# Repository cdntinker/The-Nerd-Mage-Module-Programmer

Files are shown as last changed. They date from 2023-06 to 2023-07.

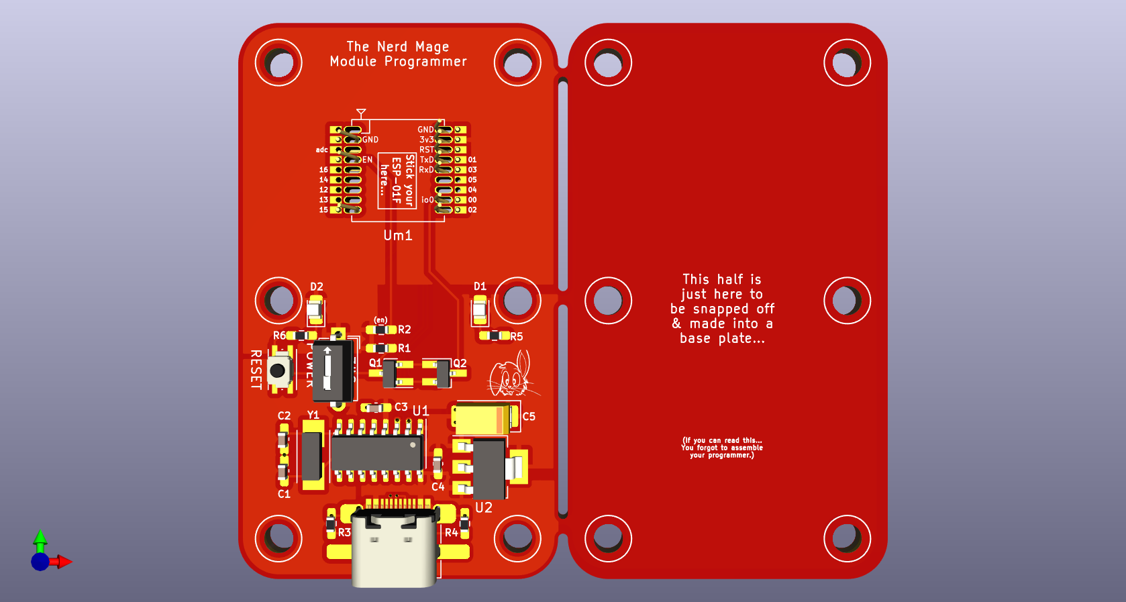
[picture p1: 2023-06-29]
Pix/ESP-01F (front).png

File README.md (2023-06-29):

# This is __The Nerd Mage Module Programmer__  Project

The original intent of this project was to simplify pre-programming ESP modules.

I started out doing up a design to help a friend program ESP-M3 modules with OTA capable firmware that he could then solder into projects to be scattered around And never directly connected again.

And, of course, The rabbits showed up & started digging holes in my desktop...  As usual...

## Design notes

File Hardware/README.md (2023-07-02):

# This is __The Nerd Mage Module Programmer__  Project

Each of the subfolders here is basically a KiCAD project.  Yes, I know there's a lot of duplication here.  One of these days, I'll figure out how to make KiCAD re-use existing schematics & board files as "libraries".

- (KiCAD Customs)
  - Custom symbols, footprints, 3D models needed for this project
    - (Just the 3D models so far...)

## The various "editions"...

- (blank)
  - The base design with no module set up
- (standalone)
  - A version with a pin header instead of a module
- ESP-01F
  - Footprint added for an ESP-01F
- ESP-01S
  - Footprint added for an ESP-01S
- ESP-M3
  - Footprint added for an ESP-M3
- ESP-12
  - Footprint added for an ESP-12 (or ESP-07)
- ESP-Wroom-32
  - Footprint added for an ESP-Wroom-32
- Seeed Wio-RP2040
  - This one is VERY MUCH a WIP
  - Building & adding a footprint for the Seeed Studios Wio-RP2040 module
- BOM.ods
  - Sort of a manually created Bill of Materials

  ## To be done

  Need to work out how to add my custom symbols, footprints & 3D models in here...

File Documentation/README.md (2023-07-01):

# This is __The Nerd Mage Module Programmer__  Project

Really should expand on this...

## Notes about the common design elements of the boards

### The __reset / io0__ "MCU Mode Select" circuit:
Transistors Q1 & Q2 are a bright idea stolen blatantly from the schematic of the Wemos D1-mini.  Basically, they cause io0 to be held low during a reset called for programatically.

So...  You can treat these programmers as nodemcu boards.

- In platformio.ini:
  - `upload_resetmethod = nodemcu`

### The CH340 UART chip:
This is a basic USB to serial chip.

The version used in the current design (CH340G) uses an external crystal for timing.

__NOTE__ that the RxD & TxD lines from this chip are swapped on their way to the module.

### The USB connector (J1):
These boards use USB-C simply for the convenience of reversability.  The USB connection is actually just USB 2.0.

R3 & R4 are there to ensure that, if your USB port on the computer is USB-C, then 5.0V is supplied to the board.

### The LEDs:
- D1
  - indicates power to the board (From USB...)
- D2
  - Indicates power to the module being programmed

### The switches:
- SW1 (pushbutton)
  - Pulls the reset line of the module low
- SW2 (slider)
  - Switches on/off power to the module

### The "Base Plate" board:
The flexyPins used for connecting the modules require space under the board.

So...  The base plate, along with 6 3mmx4mm spacers & 12 of the shortest available 3mm machine screws provide this space & protect the FlexyPins.

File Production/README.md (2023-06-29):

# This is __The Nerd Mage Module Programmer__  Project

- CH340-testing.020.AS_FABBED.tar.gz
  - is the fully tested version.
- CH340-testing.AS_FABBED.tar.gz
  - is only still here since I have a few boards of that version on hand.  The Rx & Tx lines are backwards...
- 0.5.2 (ESP12) (as fabbed).tar.gz
  - is the NEW & IMPROVED design.  This particular one is the ESP-12 programmer as requested by TheGuruOfNothing.

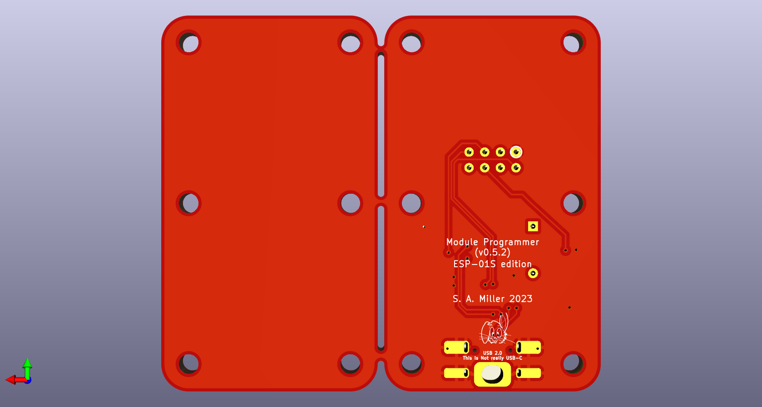
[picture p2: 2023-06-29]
Pix/ESP-01S (back).png

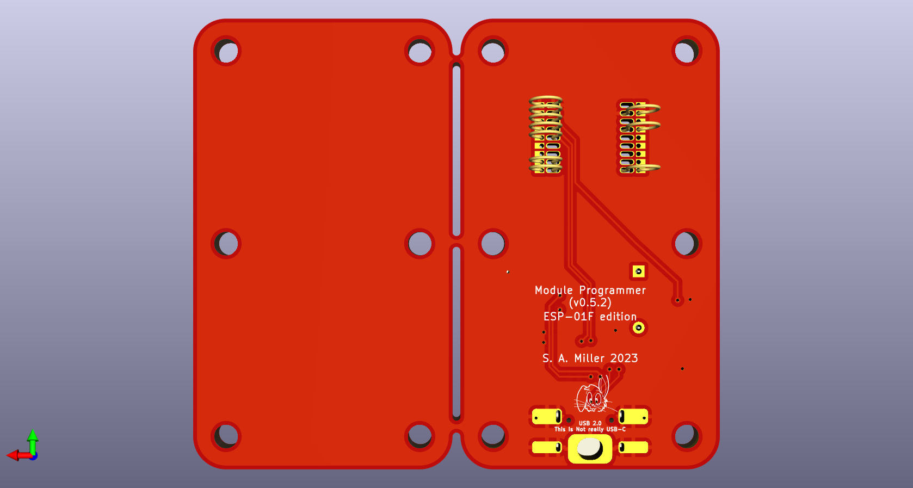
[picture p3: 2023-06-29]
Pix/ESP-01F (back).png

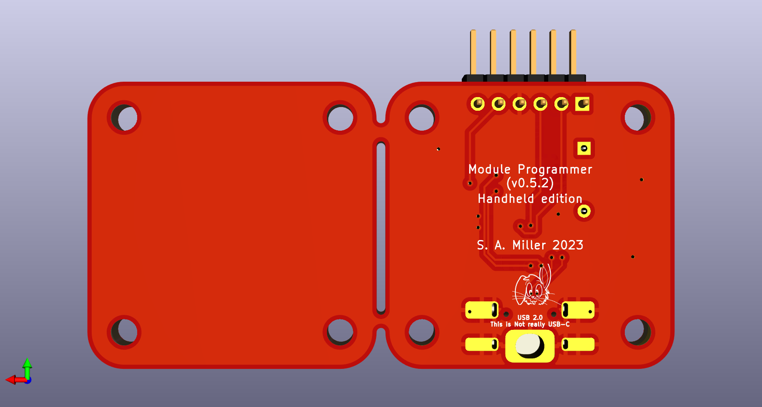
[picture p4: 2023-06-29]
Pix/Standalone (back).png

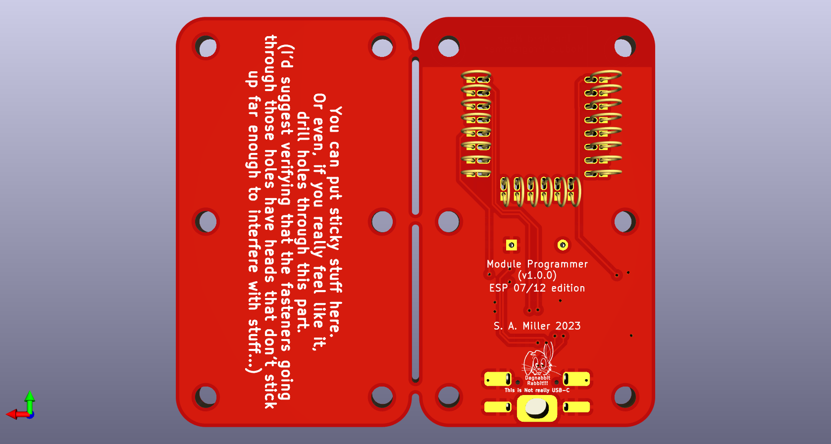
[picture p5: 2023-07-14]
Pix/ESP12 (1.0.0) (back).png

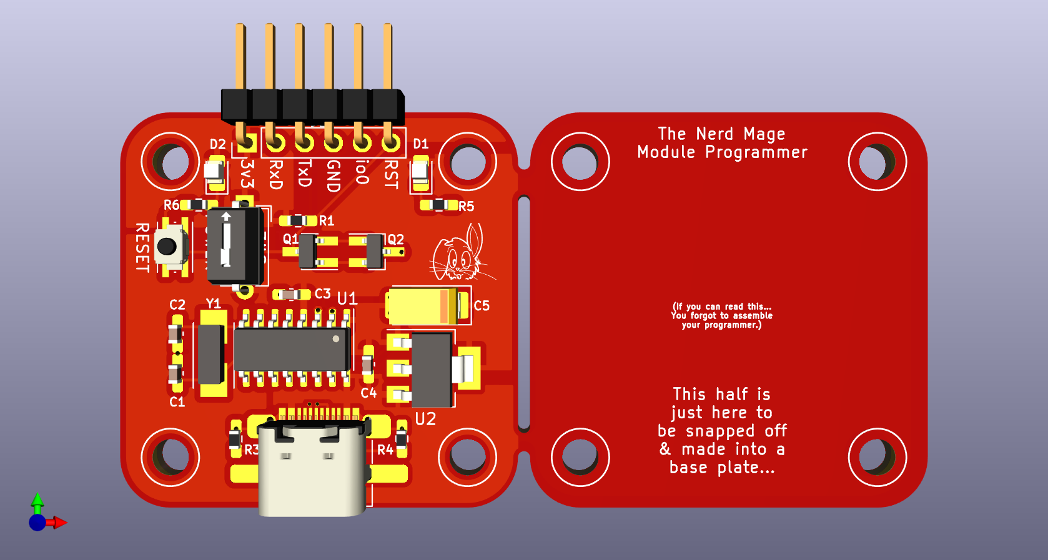
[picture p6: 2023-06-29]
Pix/Standalone (front).png

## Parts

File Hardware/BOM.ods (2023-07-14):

 |  | Value | Type | Footprint | Stock | Order? | Link
Boards
 |  |  |  |  |  |  |  | 1.5
Ics
 | U1 | CH340G | USB 2.0 Transceiver | SOP-16 | 16 |  | https://www.lcsc.com/product-detail/USB-ICs_WCH-Jiangsu-Qin-Heng-CH340G_C14267.html | 0.4805
 | U2 | AMS1117-3.3 | Linear Voltage Regulator | SOT-223 | 80 |  | https://www.lcsc.com/product-detail/Linear-Voltage-Regulators-LDO_HEERMICR-AMS1117-3-3_C5199435.html | 0.0627
Transistors
 | Q1 | MMBT3904 | NPN | SOT-23 | 70 |  | https://www.lcsc.com/product-detail/Bipolar-Transistors-BJT_GOODWORK-MMBT3904_C909754.html | 0.0057
 | Q2 | MMBT3904 | NPN | SOT-23 |  |  | https://www.lcsc.com/product-detail/Bipolar-Transistors-BJT_GOODWORK-MMBT3904_C909754.html | 0.0057
Xtals
 | Y1 | 12MHz | Quartz Crystam | 5.0x3.2x1.3 | 6 |  | https://www.lcsc.com/product-detail/Crystals_HCI-XC53G2-12-000-F20LJDT_C2842275.html | 0.1838
LEDs
 | D1 | LED | Green | 0805 | 20 |  | https://www.lcsc.com/product-detail/_Yongyu-Photoelectric-_C434432.html | 0.0123
 | D2 | LED | Blue | 0805 | 20 |  | https://www.lcsc.com/product-detail/_Yongyu-Photoelectric-_C434433.html | 0.012
Resistors
 | R1 | 10K | Thick Film | 0603 | 200 |  | https://www.lcsc.com/product-detail/Chip-Resistor-Surface-Mount_UNI-ROYAL-Uniroyal-Elec-0603WAF1002T5E_C25804.html | 0.0009
 | R2 | 10K | Thick Film | 0603 |  |  | https://www.lcsc.com/product-detail/Chip-Resistor-Surface-Mount_UNI-ROYAL-Uniroyal-Elec-0603WAF1002T5E_C25804.html | 0.0009
 | R3 | 5K1 | Thick Film | 0603 | 50 |  | https://www.lcsc.com/product-detail/Chip-Resistor-Surface-Mount_UNI-ROYAL-Uniroyal-Elec-0603WAF5101T5E_C23186.html | 0.0011
 | R4 | 5K1 | Thick Film | 0603 |  |  | https://www.lcsc.com/product-detail/Chip-Resistor-Surface-Mount_UNI-ROYAL-Uniroyal-Elec-0603WAF5101T5E_C23186.html | 0.0011
 | R5 | 2K2 | Thick Film | 0603 | 90 |  | https://www.lcsc.com/product-detail/Chip-Resistor-Surface-Mount_UNI-ROYAL-Uniroyal-Elec-0603WAF2201T5E_C4190.html | 0.0011
 | R6 | 2K2 | Thick Film | 0603 |  |  | https://www.lcsc.com/product-detail/Chip-Resistor-Surface-Mount_UNI-ROYAL-Uniroyal-Elec-0603WAF2201T5E_C4190.html | 0.0011
 | R7 | 10K | Thick Film | 0603 |  |  | https://www.lcsc.com/product-detail/Chip-Resistor-Surface-Mount_UNI-ROYAL-Uniroyal-Elec-0603WAF1002T5E_C25804.html | 0.0009
 | R8 | 10K | Thick Film | 0603 |  |  | https://www.lcsc.com/product-detail/Chip-Resistor-Surface-Mount_UNI-ROYAL-Uniroyal-Elec-0603WAF1002T5E_C25804.html | 0.0009
Caps
 | C1 | 20p | MLCC | 0603 | 40 |  | https://www.lcsc.com/product-detail/Multilayer-Ceramic-Capacitors-MLCC-SMD-SMT_YAGEO-CC0603JRNPO9BN220_C105620.html | 0.0023
 | C2 | 20p | MLCC | 0603 | 200 |  | https://www.lcsc.com/product-detail/Multilayer-Ceramic-Capacitors-MLCC-SMD-SMT_YAGEO-CC0603JRNPO9BN220_C105620.html | 0.0023
 | C3 | 10nf | MLCC | 0603 | 200 |  | https://www.lcsc.com/product-detail/Multilayer-Ceramic-Capacitors-MLCC-SMD-SMT_YAGEO-CC0603KRX7R9BB103_C100042.html | 0.0021
 | C4 | 100nf | MLCC | 0603 | 200 |  | https://www.lcsc.com/product-detail/Multilayer-Ceramic-Capacitors-MLCC-SMD-SMT_FH-Guangdong-Fenghua-Advanced-Tech-0603F104M500NT_C42998.html | 0.0022
 | C5 | 22uf | Tantalum |  | 90 |  | https://www.lcsc.com/product-detail/Tantalum-Capacitors_Vishay-Intertech-293D226X0016C2TE3_C1957020.html | 0.3234
Connectors
 | J1 | USB-C |  |  |  |  | https://www.lcsc.com/product-detail/USB-Connectors_SHOU-HAN-TYPE-C-16PIN-2MD-073_C2765186.html | 0.0523
 | Um1 | FlexyPins |  |  | 60 |  | https://www.lectronz.com/products/flexypin-pack-of-100 | 1
 |  |  |  |  | 150
Switches
 | SW1 | pushbutton |  |  | 20 |  | https://www.lcsc.com/product-detail/Tactile%20Switches_SHOU-HAN-TS273014TP-180gf-098_C2858276.html | 0.1074
 | SW2 | DIP-1 |  |  | 17 |  | https://www.lcsc.com/product-detail/DIP-Switches_C-K-SDA01H1BD_C2689618.html | 0.7732
 |  |  |  |  |  |  |  | 4.5359

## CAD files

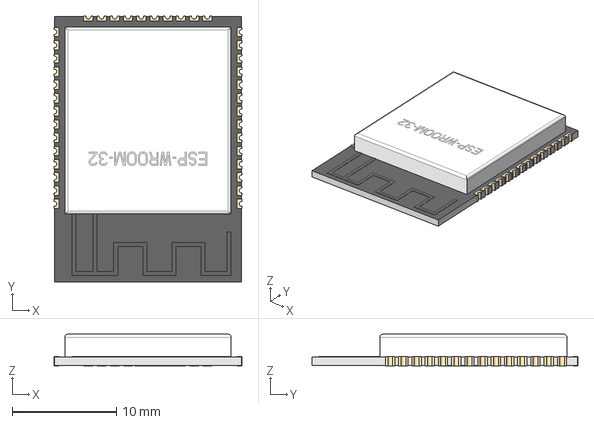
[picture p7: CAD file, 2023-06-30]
Hardware/(KiCAD Customs)/3D/ESP32/KiCAD-ESP-WROOM-32.step
18.1 x 25.5 x 3.04 mm

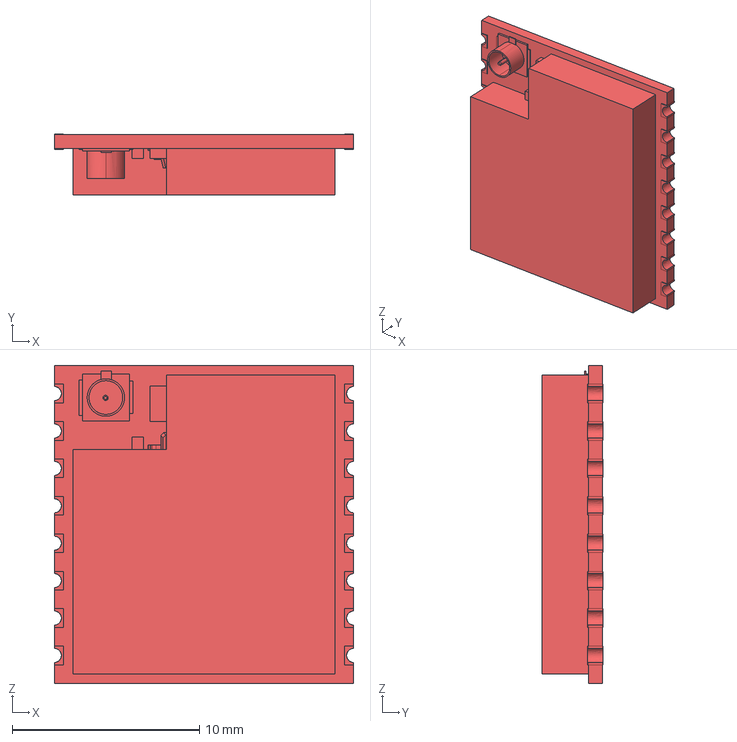
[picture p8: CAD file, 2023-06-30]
Hardware/(KiCAD Customs)/3D/ESP8266/esp-07s.stp
16.0 x 3.28 x 17.0 mm

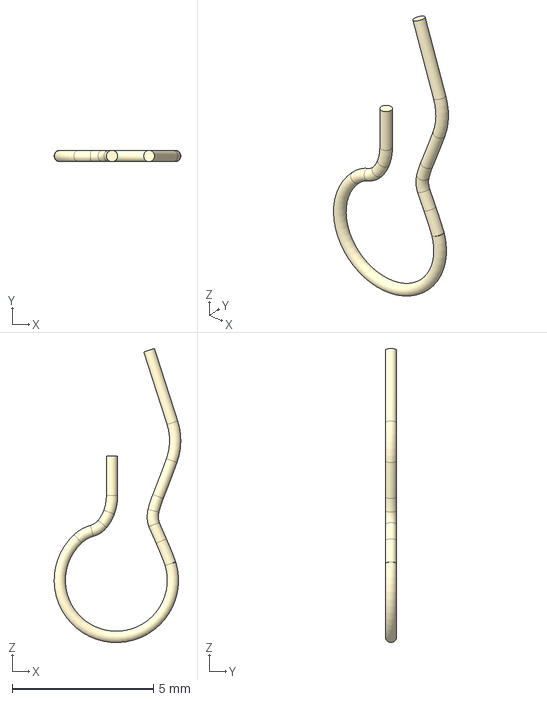
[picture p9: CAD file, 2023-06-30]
Hardware/(KiCAD Customs)/3D/flexypin.step
4.48 x 0.4 x 10.4 mm

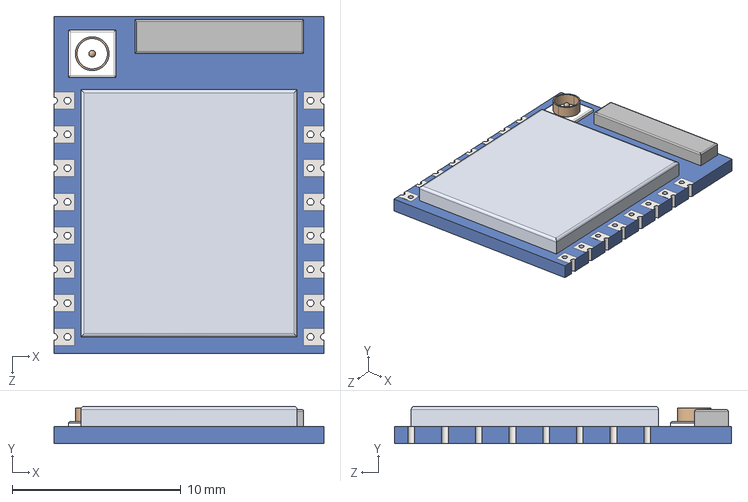
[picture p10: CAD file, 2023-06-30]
Hardware/(KiCAD Customs)/3D/ESP8266/ESP8266-ESP07.STEP
16.0 x 2.21 x 20.0 mm

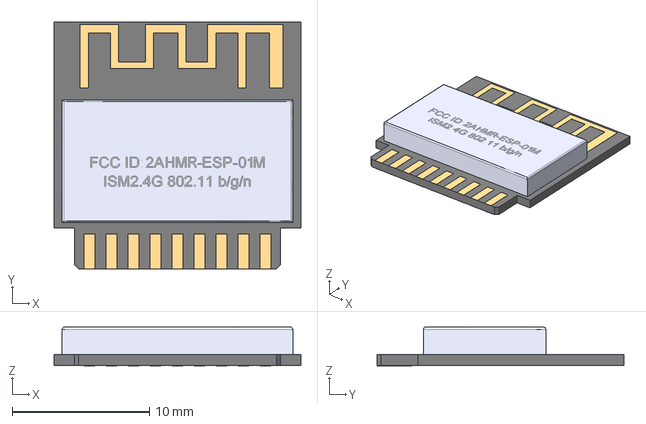
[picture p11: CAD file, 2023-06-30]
Hardware/(KiCAD Customs)/3D/ESP8266/ESP-01M.stp
18.0 x 18.0 x 2.81 mm

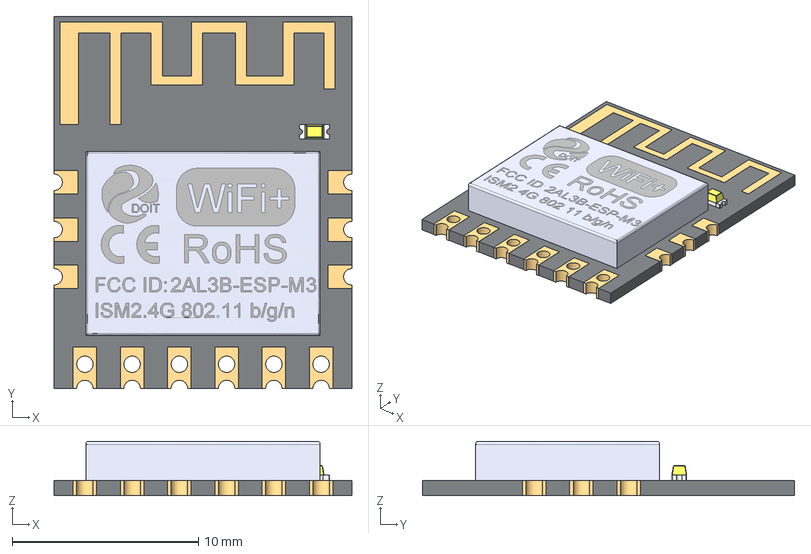
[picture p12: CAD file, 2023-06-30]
Hardware/(KiCAD Customs)/3D/ESP8266/ESP-M3.stp
16.0 x 20.0 x 2.91 mm

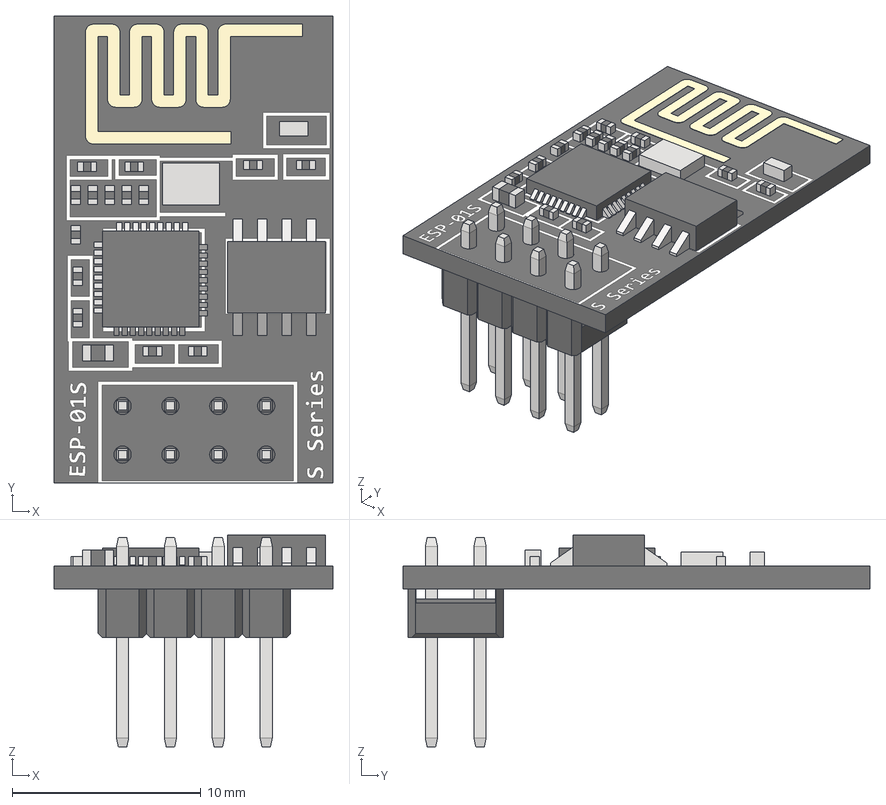
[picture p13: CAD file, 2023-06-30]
Hardware/(KiCAD Customs)/3D/ESP8266/ESP-01S (ESP8266) Board Module.step
14.8 x 24.8 x 11.2 mm
PCB
Antenna
SerialFlashMem
ESP8266EX
Male Pin Header 2x4
SmalComponent x 14
LargeComponent
LED
Crystal

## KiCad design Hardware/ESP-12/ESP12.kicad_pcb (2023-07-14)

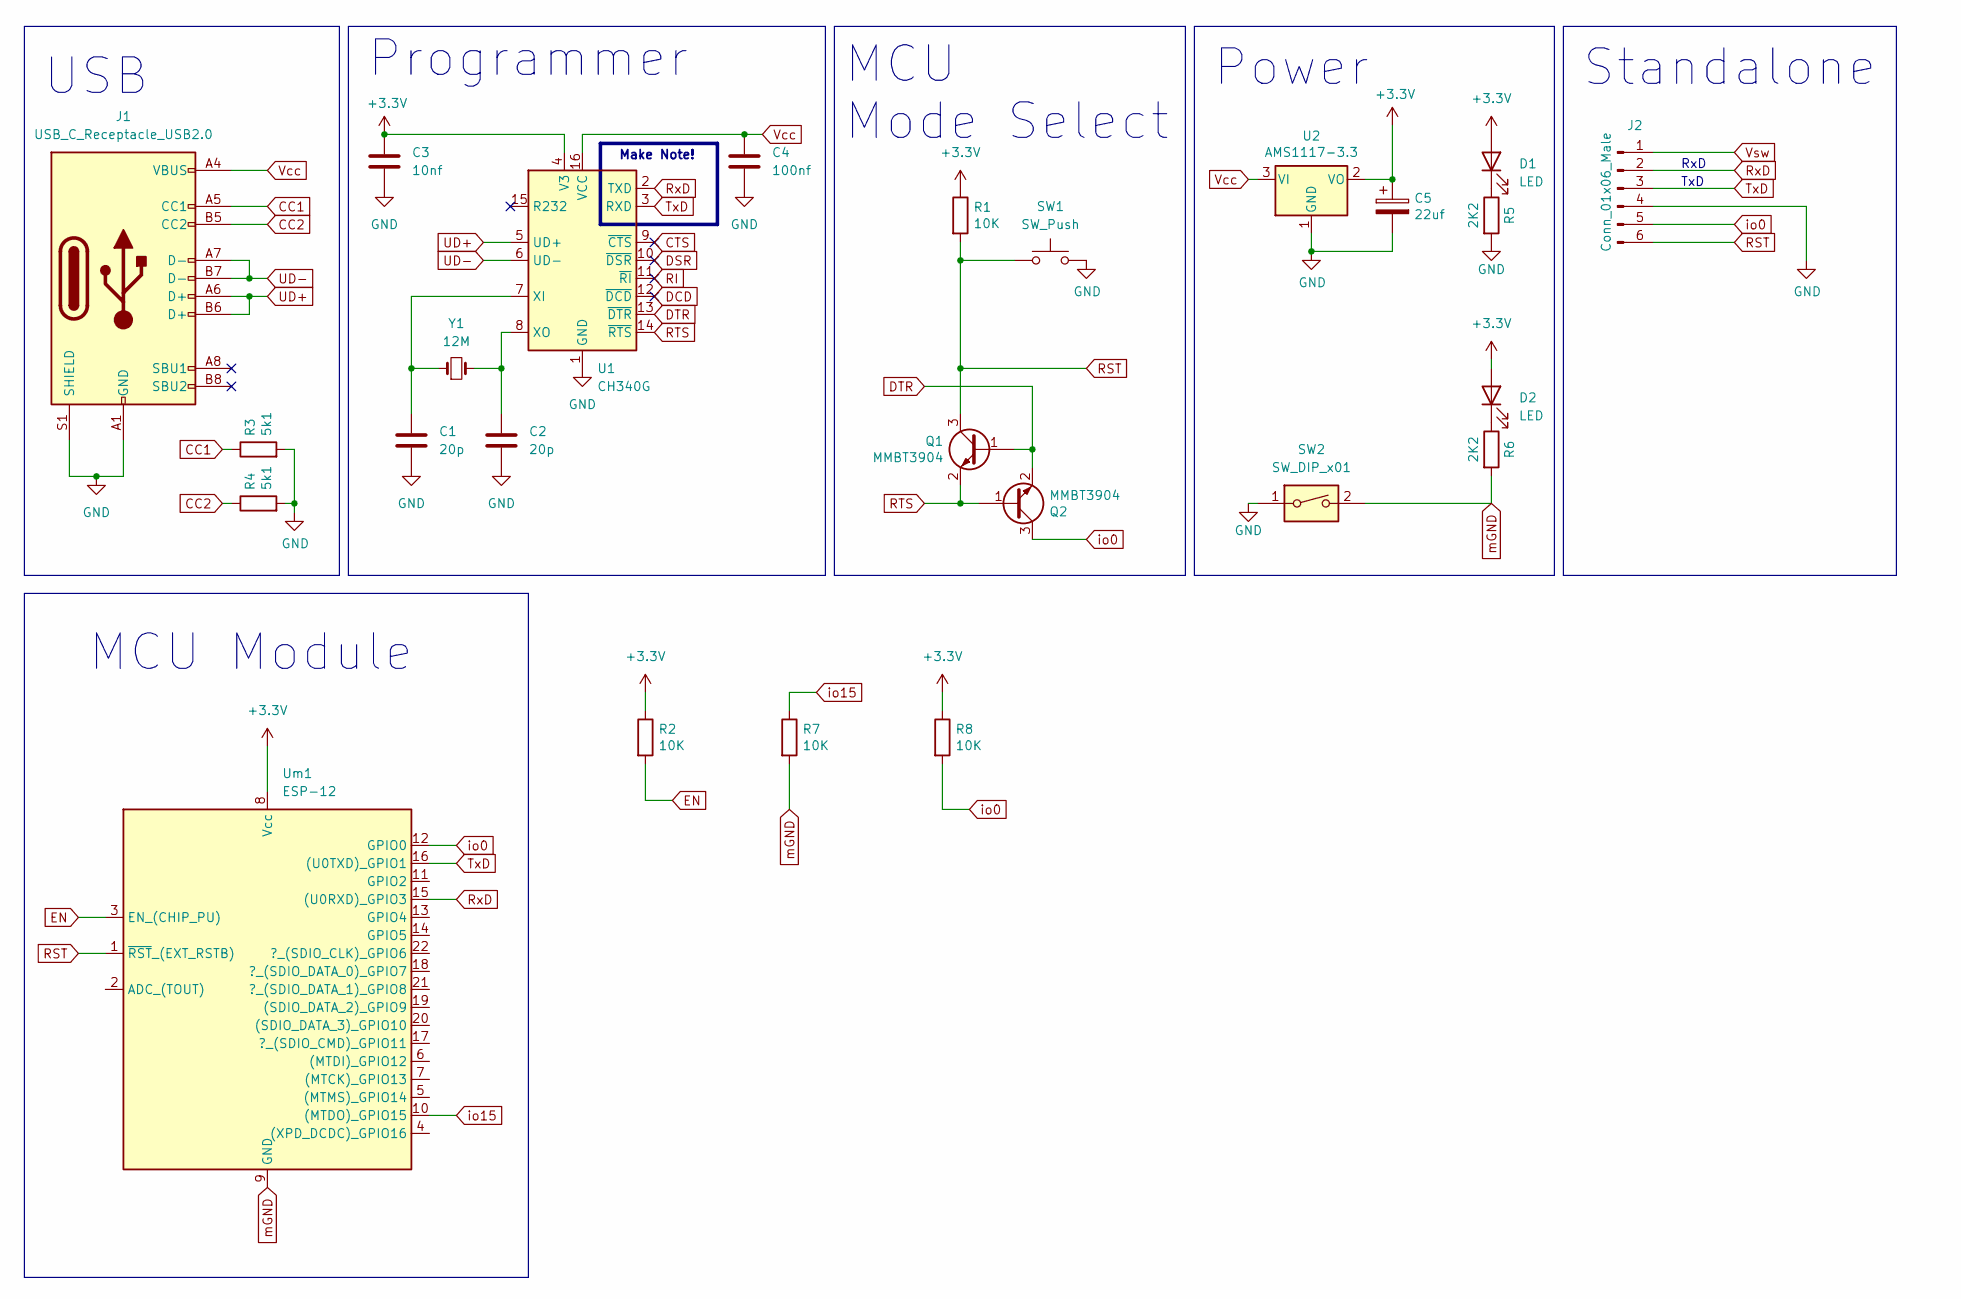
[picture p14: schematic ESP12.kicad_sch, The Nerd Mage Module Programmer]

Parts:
C1, C2: 20p; C_0603_1608Metric_Pad1.08x0.95mm_HandSolder; LCSC C408549 (20pf C325469)
C3: 10nf; C_0603_1608Metric_Pad1.08x0.95mm_HandSolder; LCSC C161232
C4: 100nf; C_0603_1608Metric_Pad1.08x0.95mm_HandSolder; LCSC C235731
C5: 22uf; CP_EIA-6032-28_Kemet-C_Pad2.25x2.35mm_HandSolder
D1, D2: LED; LED_0805_2012Metric_Pad1.15x1.40mm_HandSolder
J1: USB_C_Receptacle_USB2.0; USB_C_Receptacle_HRO_TYPE-C-31-M-12
J2: Conn_01x06_Male; PinHeader_1x06_P2.54mm_Vertical
Q1, Q2: MMBT3904; SOT-23_Handsoldering
R1, R2, R7, R8: 10K; R_0603_1608Metric_Pad0.98x0.95mm_HandSolder
R3, R4: 5k1; R_0603_1608Metric_Pad0.98x0.95mm_HandSolder
R5, R6: 2K2; R_0603_1608Metric_Pad0.98x0.95mm_HandSolder
SW1: SW_Push; SW_Push_TS273014TP; LCSC C2858276
SW2: SW_DIP_x01; SW_DIP_SPSTx01_Slide_6.7x4.1mm_W7.62mm_P2.54mm_LowProfile
U1: CH340G; SOIC-16_3.9x9.9mm_P1.27mm; LCSC C14267
U2: AMS1117-3.3; SOT-223-3_TabPin2
Um1: ESP-12; ESP-12 (FlexyPin)
Y1: 12M; Crystal_SMD_5032-2Pin_5.0x3.2mm; LCSC C2842275

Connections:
+3.3V: C3.1, C5.1, D1.2 (A), D2.2 (A), R1.1, R2.1, R8.1, U1.4 (V3), U2.2 (VO), Um1.8 (Vcc)
CC1: J1.A5 (CC1), R3.1
CC2: J1.B5 (CC2), R4.1
CTS: U1.9 (~CTS)
DCD: U1.12 (~DCD)
DSR: U1.10 (~DSR)
DTR: Q1.1 (B), Q2.2 (E), U1.13 (~DTR)
EN: R2.2, Um1.3 (EN_(CHIP_PU))
GND: C1.2, C2.2, C3.2, C4.2, C5.2, J1.A1 (GND), J1.A12 (GND), J1.B1 (GND), J1.B12 (GND), J1.S1 (SHIELD), J2.4, R3.2, R4.2, R5.2, SW1.2, SW2.1, U1.1 (GND), U2.1 (GND)
unnamed: C1.1, U1.7 (XI), Y1.1
unnamed: C2.1, U1.8 (XO), Y1.2
unnamed: D1.1 (K), R5.1
unnamed: D2.1 (K), R6.1
RI: U1.11 (~RI)
RST: J2.6, Q1.3 (C), R1.2, SW1.1, Um1.1 (~RST_(EXT_RSTB))
RTS: Q1.2 (E), Q2.1 (B), U1.14 (~RTS)
RxD: J2.2, U1.2 (TXD), Um1.15 ((U0RXD)_GPIO3)
TxD: J2.3, U1.3 (RXD), Um1.16 ((U0TXD)_GPIO1)
UD+: J1.A6 (D+), J1.B6 (D+), U1.5 (UD+)
UD-: J1.A7 (D-), J1.B7 (D-), U1.6 (UD-)
Vcc: C4.1, J1.A4 (VBUS), J1.A9 (VBUS), J1.B4 (VBUS), J1.B9 (VBUS), U1.16 (VCC), U2.3 (VI)
io0: J2.5, Q2.3 (C), R8.2, Um1.12 (GPIO0)
io15: R7.1, Um1.10 ((MTDO)_GPIO15)
mGND: R6.2, R7.2, SW2.2, Um1.9 (GND)

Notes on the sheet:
Make Note!
Power
USB
MCU Mode Select
TxD
Standalone
RxD
MCU Module
Programmer

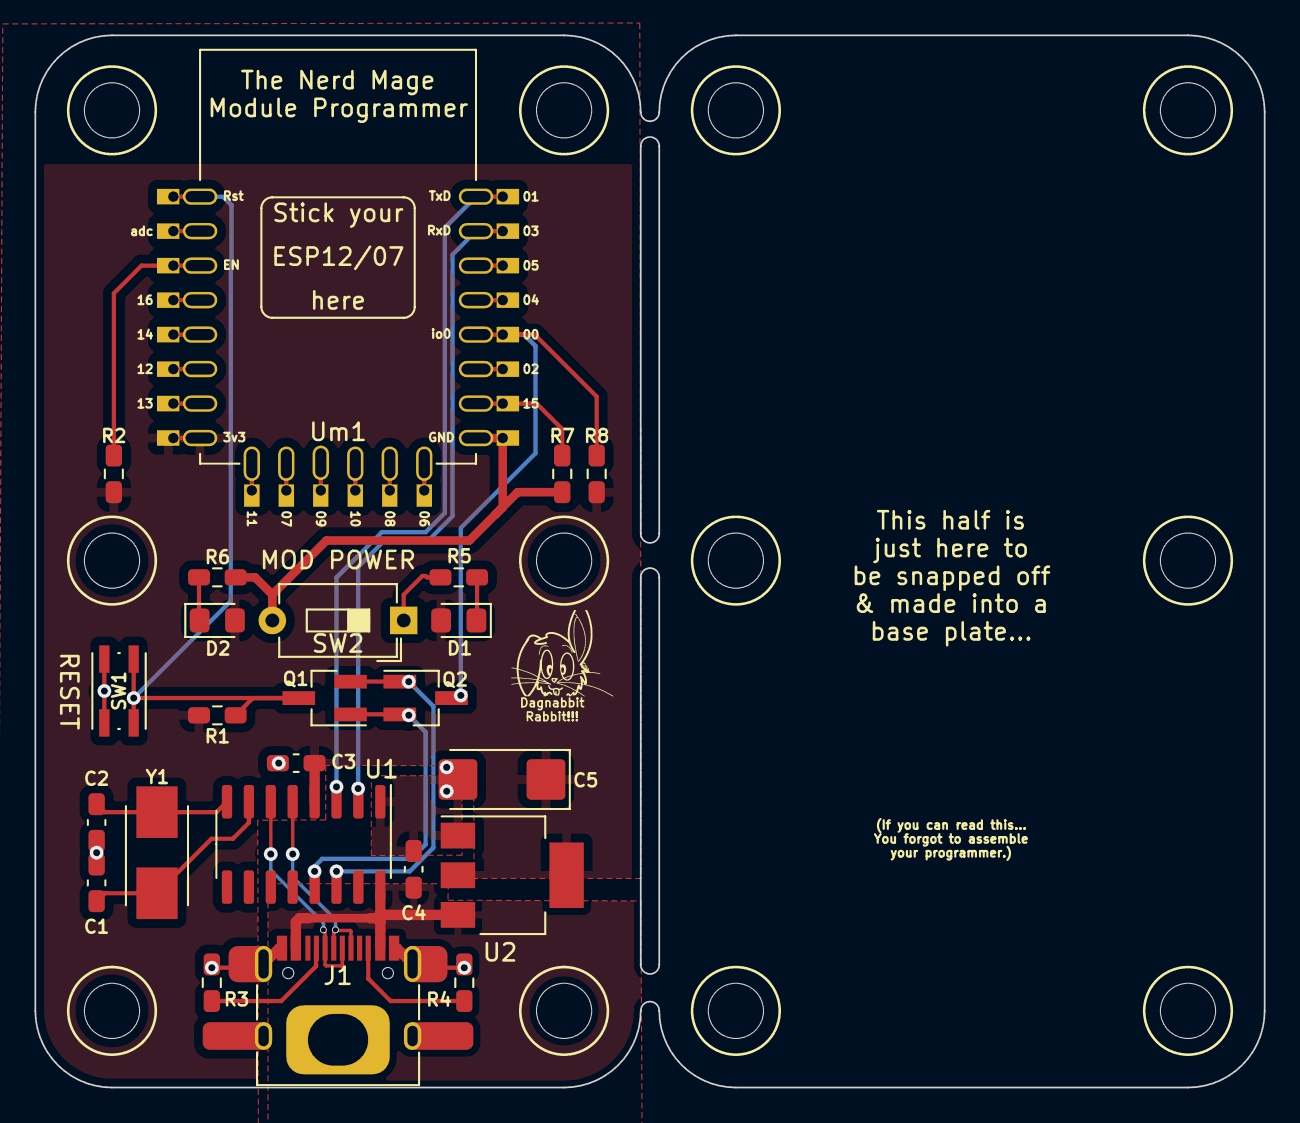
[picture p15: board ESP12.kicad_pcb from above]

Board: 2 copper layers, 71.3 x 61.0 mm, 24 parts (0 on the bottom side), 20 nets.

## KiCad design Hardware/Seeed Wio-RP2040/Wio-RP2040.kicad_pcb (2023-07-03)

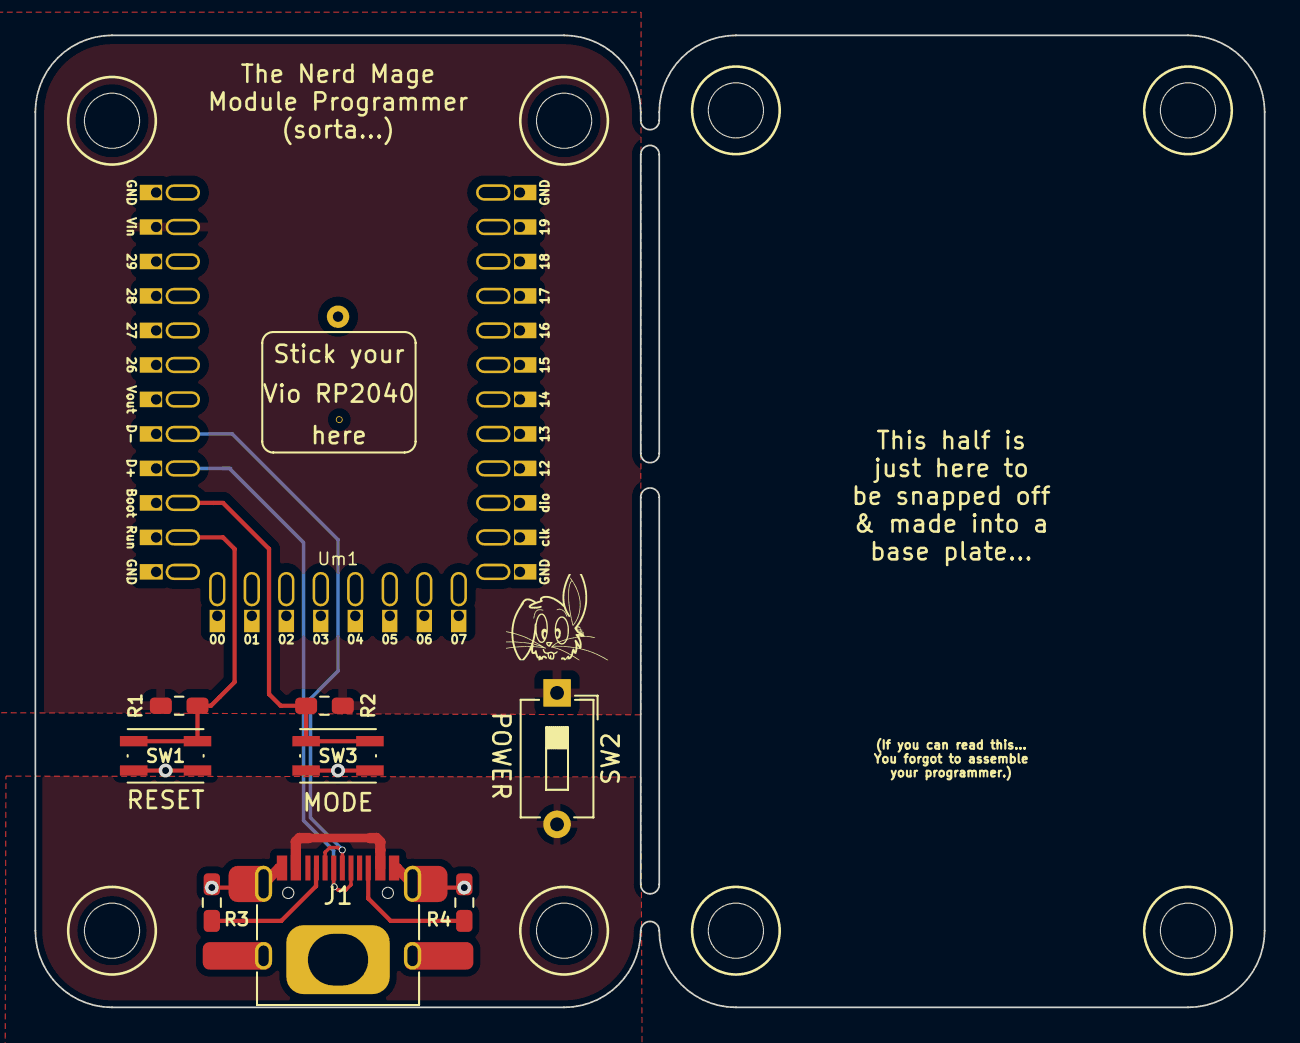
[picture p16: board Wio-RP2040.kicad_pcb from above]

Board: 2 copper layers, 71.3 x 56.4 mm, 9 parts (0 on the bottom side), 9 nets.

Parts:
J1: USB_C_Receptacle_USB2.0; USB_C_Receptacle_HRO_TYPE-C-31-M-12
R1, R2: 10K; R_0603_1608Metric_Pad0.98x0.95mm_HandSolder
R3, R4: 5k1; R_0603_1608Metric_Pad0.98x0.95mm_HandSolder
SW1, SW3: SW_Push; SW_Push_TS273014TP
SW2: SW_DIP_x01; SW_DIP_SPSTx01_Slide_6.7x4.1mm_W7.62mm_P2.54mm_LowProfile
Um1: Wio-RP2040; Wio_RP2040 (FlexyPin)

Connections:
CC1: J1.A5 (CC1), R3.1
CC2: J1.B5 (CC2), R4.1
GND: J1.A1 (GND), J1.A12 (GND), J1.B1 (GND), J1.B12 (GND), J1.S1 (SHIELD), R3.2, R4.2, SW1.2, SW3.2, Um1.1 (GND), Um1.12 (GND), Um1.21 (GND), Um1.32 (GND), Um1.33 (GND)
RST: R1.2, SW1.1, Um1.11 (~Run_(RST))
UD+: J1.A6 (D+), J1.B6 (D+), Um1.9 (USB_D+)
UD-: J1.A7 (D-), J1.B7 (D-), Um1.8 (USB_D-)
Vcc: J1.A4 (VBUS), J1.A9 (VBUS), J1.B4 (VBUS), J1.B9 (VBUS), SW2.2
Vsw: R1.1, R2.1, SW2.1, Um1.2 (Vin)
mode: R2.2, SW3.1, Um1.10 (~Boot)

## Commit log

2023-06-29 Added M3 version
    [ESP-M3.kicad_pcb, ESP-M3.kicad_sch]
2023-06-29 01S & 01F added
    [ESP-01F.kicad_pcb, ESP-01F.kicad_sch, ESP-01S.kicad_pcb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]
2023-06-29 Fixin' up Edition names
    [ESP-M3.kicad_pcb, ESP-M3.kicad_sch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]
2023-06-30 Startin' to add (KiCAD Customs) folder
    [BOM.ods, ESP-01M.stp, ESP-01S (ESP8266) Board Module.step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]
2023-06-30 Fixed more 3D...
    [ESP-01F.kicad_pcb, ESP-M3.kicad_pcb, ESP12.kicad_pcb]
2023-06-30 Attempting to add my custom bits...
    [ESP-01F.kicad_pcb]
2023-07-01 Starting extensive schematic tidy-up
    [ESP12.kicad_sch]
2023-07-02 WIP... Seeed Wio-RP2040
    [Wio-RP2040.kicad_pcb, Wio-RP2040.kicad_sch]
2023-07-03 werkin on da RP2040
    [Wio-RP2040.kicad_pcb, Wio-RP2040.kicad_sch]
2023-07-14 Getting up to rev 1
    [ESP12.kicad_pcb, ESP12.kicad_sch]
2023-07-14 gerbers ready(?)
    [ESP12-B_Cu.gbr, ESP12-B_Mask.gbr, ESP12-B_Paste.gbr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]
2023-07-14 updating sheet info
    [ESP12.kicad_pcb, ESP12.kicad_sch]
2023-07-14 v1.0.0 gerbers submitted
    [ESP12-B_Cu.gbr, ESP12-B_Mask.gbr, ESP12-B_Paste.gbr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]
2023-07-14 updated BOM & noted ESP-12 1.0.0 production
    [BOM.ods]
